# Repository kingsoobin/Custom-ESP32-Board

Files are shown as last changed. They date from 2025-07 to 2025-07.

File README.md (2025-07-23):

# Custom-ESP32-Board

## Introduction
This is where I keep all my files and progress for my custom ESP32 board design and assembly on Altium Designer. 

## Log
### Schematic Library & Schematic Connection
1. Find the ESP32-S3-DevKitM-1 manual on EspressIF's DevKits. Downloaded manual and schematic for the MINI-1
2. Identify components in schematic and find in Digikey. Find the manufactuer's product number to search for components on LCSC Electronics. Check availability before importing Digikey Part Number for component information into Altium's Manufacturer's Part Search
3. Create new component in SCH Library and import LCSC part number. Create component.
4. Import components into main schematic and refer to EspressIF's schematic to make connections
5. Both created own components and also imported downloaded components
6. Learned that for important pins, I can use two 27 resistors to improve signal quality and also if debugging needs to be done later that requires this pin to be disconnected, I can simply remove these resistors
7. Original schematic is using microUSB, but I want to use USB-C -> went to 99Tech to search for boards that use USB-C to look at schematic to see how to connect for my board -> find MOLEX USB-C connector
8. Assemble PCB schematic for USB-C based on 99Tech's schematic
9. Learned that I can use a jumper instead of diode. Used jumper to connect 5V of USB connectors 1 and 2 to 5V source
10. Learned about TVS Diodes used as protection.
11. Created a 5V to 3.3V converter using a regulator. IC -> Power Management -> Voltage Regulators (Low drop out regulators)
12. Read datasheet of regulator to see how it needs to be connected. In this case, it was recommended for 10uF capacitor on output with ESR no more than 3 ohms. It also uses 10uF capacitor in INPUT, but looking at the USB 2.0 specification max capacitance on power, 10uF is the recommended max. So opted to look for smallest possible in the datasheet (1uF to 10uF).
13. Created component that handles USB Connector to Serial Port
### Footprints
14. Download and import .SchLib and .step files from Digikey and/or SnapEDA and/or 3DContentCentral for standard components: ie. resistor, capacitor
15. Read drawing for more complex components (ie. headers) to create own footprint on Footprint Wizard in Altium (Dual In-line Packages): input hole dimensions
16. referred to jlcPCB capabilities to see what is the smallest text I can put on the pcb when labeling
17. Created SMD component footprint (diode)
18. For all the components that needed a footprint created, I went to its datasheet and looked for the Recommended Solder Pad Footprint for dimensions to create footprint on Footprint Wizard
19. Download footprint to all components in sch library and update schematic.
### Board Creation
20. Go back to schematic sheet for esp32 dev kit to see board dimensions
21. Place main components first before arranging the smaller one. I used the Sequentially Reposition Selected Components tool to stay organized and efficient.
### Board Connections
22. Went to jlcPCB capabilities sheet again to look at the minimum trace width and spacing, minv via hole size, solder mask expansion, and minimum clearance (pad to pad clearance) to set the rules.
23. Made rules to override component clearance for the 0OHM pairs
24. placing VIAs to connect from top board to bottom board

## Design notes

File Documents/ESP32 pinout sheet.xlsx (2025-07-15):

1 | GND_01
2 | GND_02
3 | 3V3
4 | GPIO0/RTC_GPIO0
5 | GPIO1/RTC_GPIO1/TOUCH1/ADC1_CH0
6 | GPIO2/RTC_GPIO2/TOUCH2/ADC1_CH1
7 | GPIO3/RTC_GPIO3/TOUCH3/ADC1_CH2
8 | GPIO4/RTC_GPIO4/TOUCH4/ADC1_CH3
9 | GPIO5/RTC_GPIO5/TOUCH5/ADC1_CH4
10 | GPIO6/RTC_GPIO6/TOUCH6/ADC1_CH5
11 | GPIO7/RTC_GPIO7/TOUCH7/ADC1_CH6
12 | GPIO8/RTC_GPIO8/TOUCH8/ADC1_CH7/SUBSPICS1
13 | GPIO9/RTC_GPIO9/TOUCH9/ADC1_CH8/FSPIHD/SUBSPIHD
14 | GPIO10/RTC_GPIO10/TOUCH10/ADC1_CH9/FSPICS0/FSPIIO4/SUBSPICS0
15 | GPIO11/RTC_GPIO11/TOUCH11/ADC2_CH0/FSPID/FSPIIO5/SUBSPID
16 | GPIO12/RTC_GPIO12/TOUCH12/ADC2_CH1/FSPICLK/FSPIIO6/SUBSPICLK
17 | GPIO13/RTC_GPIO13/TOUCH13/ADC2_CH2/FSPIQ/FSPIIO7/SUBSPIQ
18 | GPIO14/RTC_GPIO14/TOUCH14/ADC2_CH3/FSPIWP/FSPIDQS/SUBSPIWP
19 | GPIO15/RTC_GPIO15/U0RTS/ADC2_CH4/XTAL_32K_P
20 | GPIO16/RTC_GPIO16/U0CTS/ADC2_CH5/XTAL_32K_N
21 | GPIO17/RTC_GPIO17/U1TXD/ADC2_CH6
22 | GPIO18/RTC_GPIO18/U1RXD/ADC2_CH7/CLK_OUT3
23 | USB_D-/RTC_GPIO19/GPIO19/U1RTS/ADC2_CH8/CLK_OUT2
24 | USB_D+/RTC_GPIO20/GPIO20/U1CTS/ADC2_CH9/CLK_OUT1
25 | GPIO21/RTC_GPIO21
26 | GPIO26/SPICS1
27 | GPIO47/SPICLK_P_DIFF/SUBSPICLK_P_DIFF
28 | GPIO33/SPIIO4/FSPIHD/SUBSPIHD
29 | GPIO34/SPIIO5/FSPICS0/SUBSPICS0
30 | GPIO48/SPICLK_N_DIFF/SUBSPICLK_N_DIFF
31 | GPIO35/SPIIO6/FSPID/SUBSPID
32 | GPIO36/SPIIO7/FSPICLK/SUBSPICLK
33 | GPIO37/SPIDQS/FSPIQ/SUBSPIQ
34 | GPIO38/FSPIWP/SUBSPIWP
35 | MTCK/GPIO39/CLK_OUT3/SUBSPICS1
36 | MTDO/GPIO40/CLK_OUT2
37 | MTDI/GPIO41/CLK_OUT1
38 | MTMS/GPIO42
39 | U0TXD/GPIO43/CLK_OUT1
40 | U0RXD/GPIO44/CLK_OUT2
41 | GPIO45
42 | GND
43 | GND
44 | GPIO46
45 | EN
46 | GND_46
47 | GND_47
48 | GND_48
49 | GND_49
50 | GND_50
51 | GND_51
52 | GND_52
53 | GND_53
54 | GND_54
55 | GND_55
56 | GND_56
57 | GND_57
58 | GND_58
59 | GND_59
60 | GND_60
61 | GND_61
62 | GND_62
63 | GND_63
64 | GND_64
65 | GND_65
66 | GND_66
67 | GND_67
68 | GND_68
69 | GND_69
70 | GND_70
71 | GND_71
72 | GND_72
73 | GND_73

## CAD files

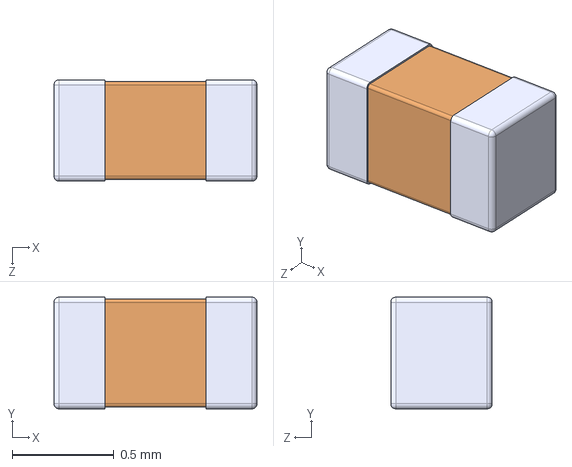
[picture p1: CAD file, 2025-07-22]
3D/CL05A105KL5NRNC.STEP
1.00 x 0.55 x 0.5 mm

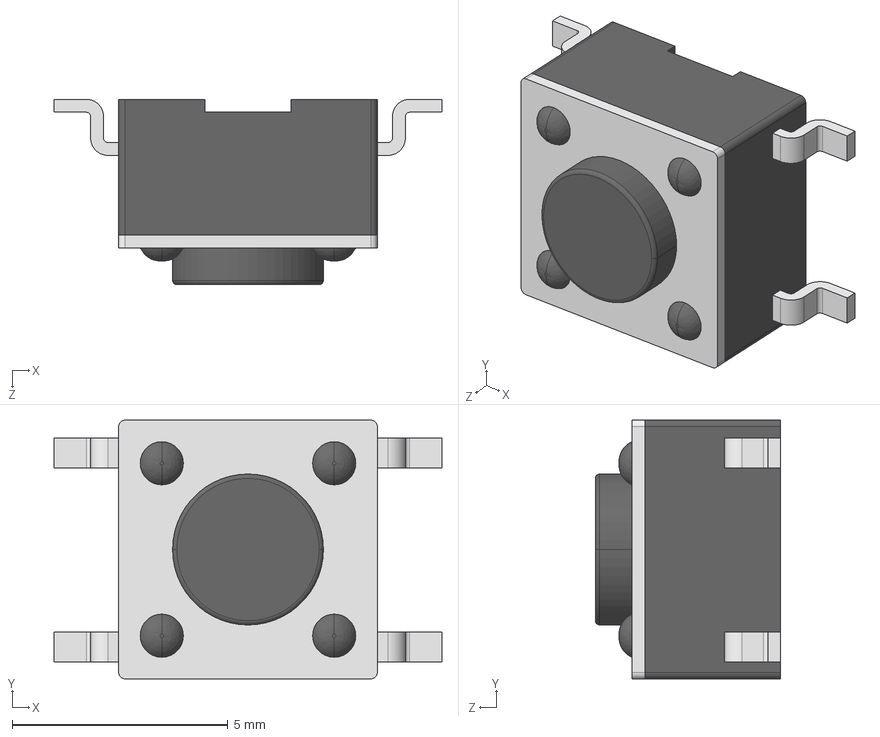
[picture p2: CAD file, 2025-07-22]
3D/User Library-PTS645SL43SMTR92-LFS.STEP
9.00 x 6.00 x 4.30 mm

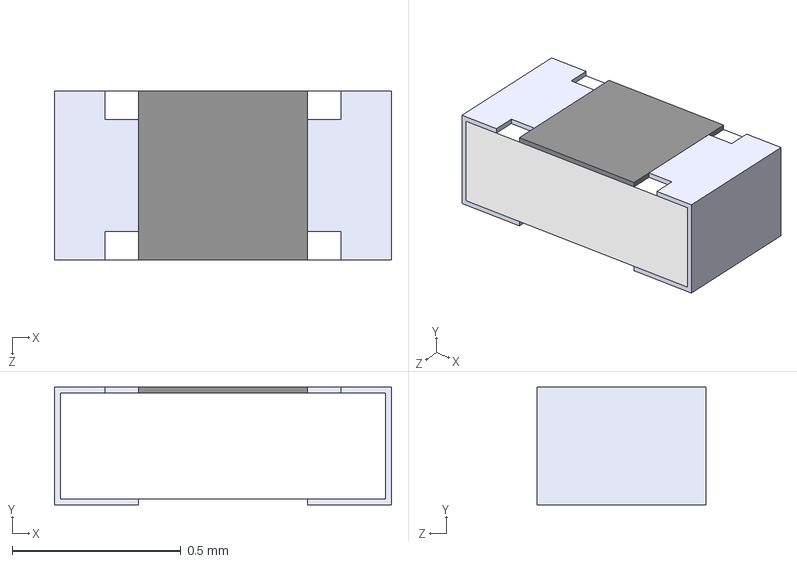
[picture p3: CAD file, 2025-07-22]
3D/RESC1005X35N.step
1 x 0.35 x 0.5 mm

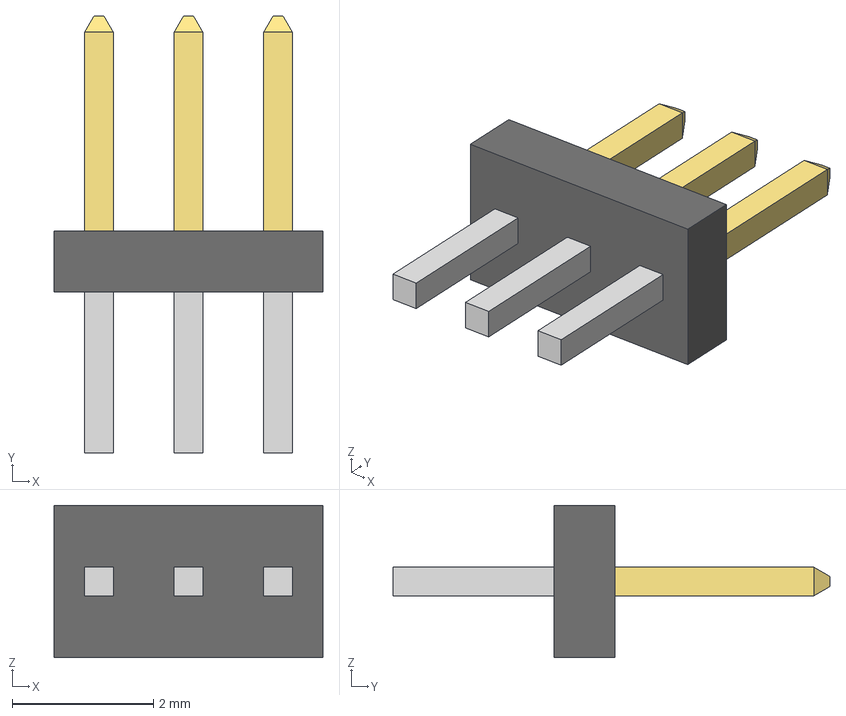
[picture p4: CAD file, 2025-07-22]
3D/FTS-103-01-F-S.stp
3.81 x 6.20 x 2.16 mm
FTS-103-01-F-S_body
FTS-103-01-F-S_pins1
FTS-103-01-F-S_pins2

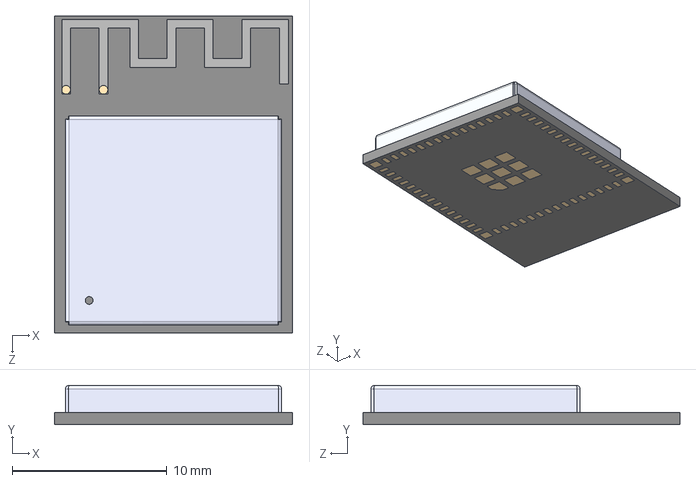
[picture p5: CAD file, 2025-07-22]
3D/ESP32-S3-MINI-1-N8--3DModel-STEP-510211.STEP
15.4 x 2.55 x 20.5 mm

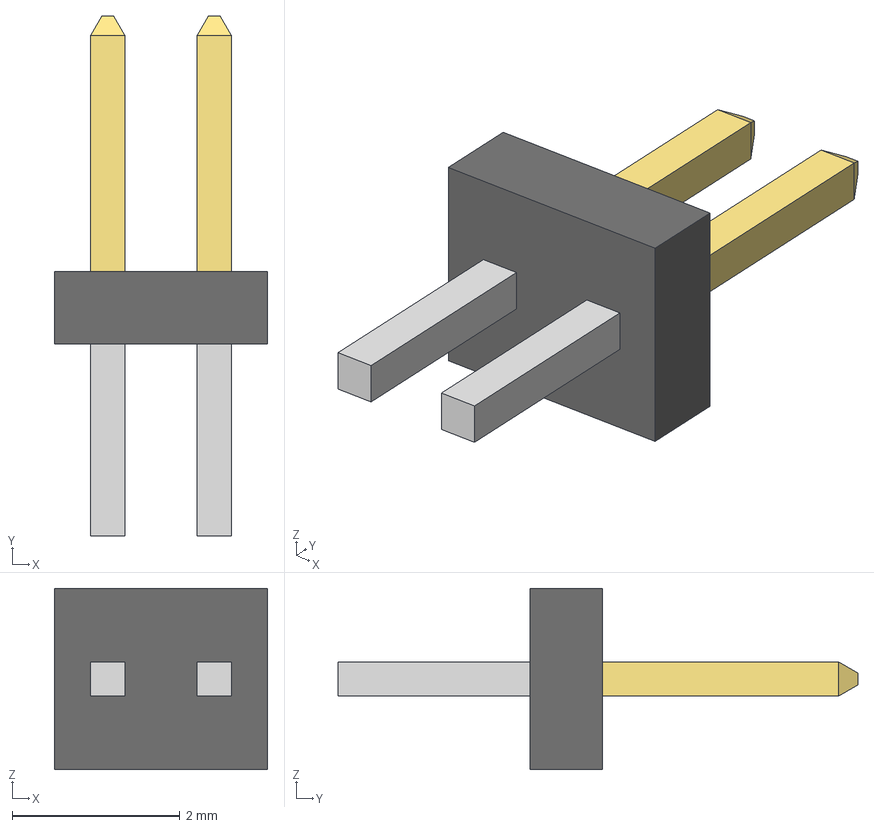
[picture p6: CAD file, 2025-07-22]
3D/FTS-102-01-F-S.stp
2.54 x 6.20 x 2.16 mm
FTS-102-01-F-S_body
FTS-102-01-F-S_pins1
FTS-102-01-F-S_pins2

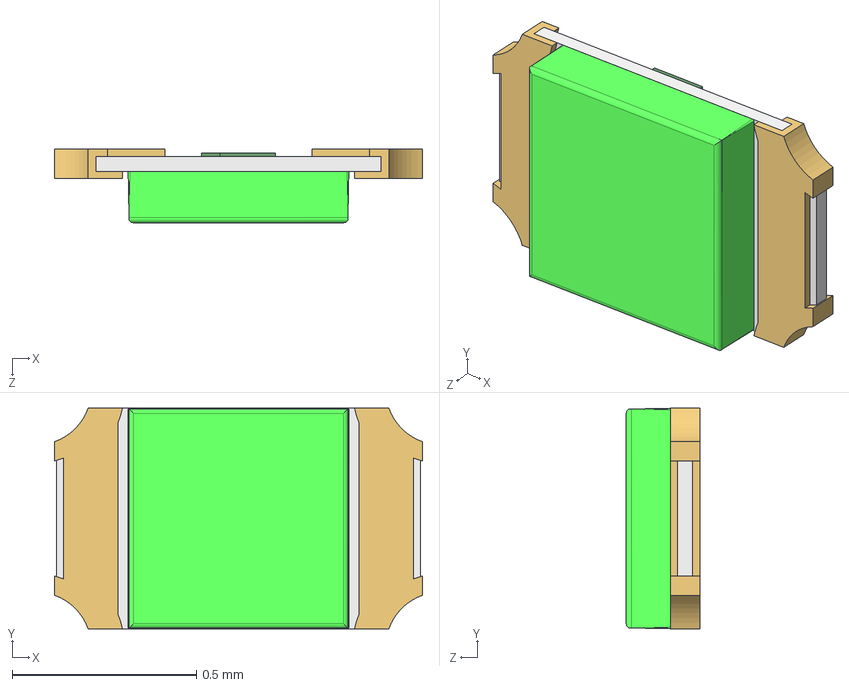
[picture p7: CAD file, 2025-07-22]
3D/User Library-LED_1006_G.STEP
1.00 x 0.6 x 0.2 mm
Grⁿn
Cut005_(Mirror_#1)

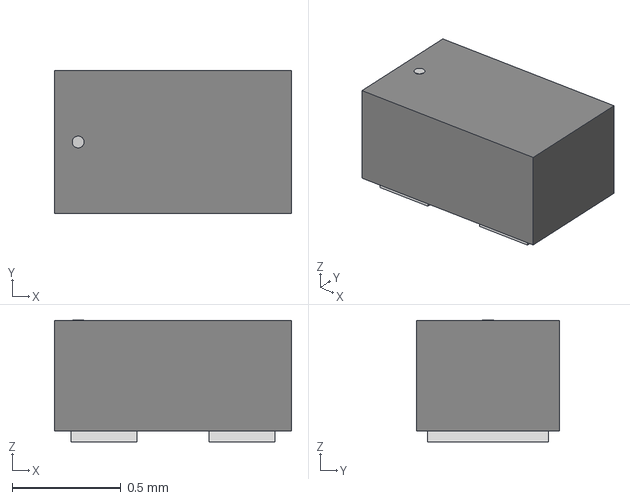
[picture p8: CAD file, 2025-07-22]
3D/RTVS_SOD882_LTF.step
1.09 x 0.66 x 0.561 mm

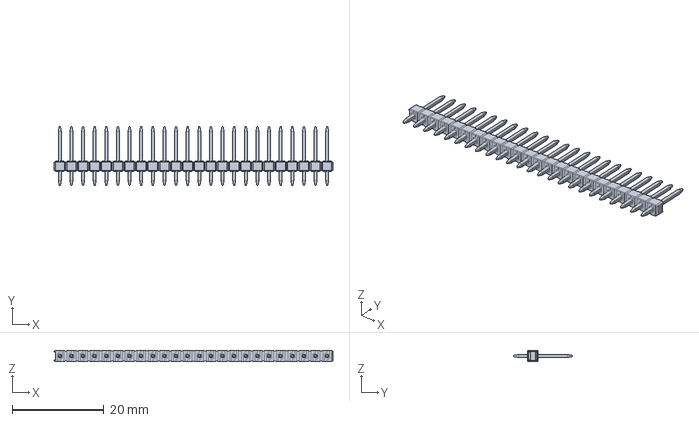
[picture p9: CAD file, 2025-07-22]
3D/022284245.stp
61.0 x 12.8 x 2.49 mm

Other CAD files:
3D/User Library-LED_1006_R.STEP

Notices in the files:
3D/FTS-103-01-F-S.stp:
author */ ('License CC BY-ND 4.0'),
